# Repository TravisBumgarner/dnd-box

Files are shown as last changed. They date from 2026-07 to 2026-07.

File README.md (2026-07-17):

# dnd_box — DND status cube

A battery-powered "Do Not Disturb" cube built on a **Seeed XIAO ESP32-C6**. An
**ADXL345** accelerometer senses which face points **up**, and the matching colored
LED lights to show your status:

| Face up | LED | Meaning |
| --- | --- | --- |
| Front | 🔴 Red | Busy / do not disturb |
| Left | 🟢 Green  | Available |
| Right | 🟡 Yellow | Semi-Available |
| Back | 🔵 Blue | Who knows |
| Top | — (off) | Idle / off |
| Bottom  | — (off) | Charge side (USB-C port) |

Only one LED is lit at a time. Charging is independent of status — the cube keeps
showing the orientation color while plugged in. After sitting idle on an off side for
30 s it **deep-sleeps** and **wakes on movement** (ADXL345 activity interrupt → D0).

## Wiring

Wiring diagram

LEDs are **active-HIGH**: `GPIO → 330Ω → LED anode`, `LED cathode → GND`. The ADXL345
runs in I²C mode — tie its `CS→VCC` and `SDO→GND` (address `0x53`); most breakouts do
this already.

| From (XIAO) | GPIO | To |
| --- | ---- | -- |
| D7  | 17 | 330Ω → Blue LED → GND |
| D8  | 19 | 330Ω → Green LED → GND |
| D9  | 20 | 330Ω → Yellow LED → GND |
| D10 | 18 | 330Ω → Red LED → GND |
| D4 · SDA | 22 | ADXL345 SDA |
| D5 · SCL | 23 | ADXL345 SCL |
| D0 · INT | 0  | ADXL345 INT1 (must be an LP GPIO for deep-sleep wake) |
| 3V3 | — | ADXL345 VCC (+ CS) |
| GND | — | ADXL345 GND (+ SDO), LED cathodes |
| BAT+ / BAT− | — | LiPo battery (charges via USB-C) |

## One-time setup

```sh
./setup.sh
```

Installs `arduino-cli` (Homebrew), the Espressif `esp32` core, and confirms the board.

## Calibrate

Every cube's "up" vectors differ, so record them once:

```sh
./upload.sh calibrate
```

This flashes the calibration tool and walks you through it: for each side, rotate so
that face is **up**, hold still, and press **Enter**. It captures the vectors straight
into `firmware/config.h` and then flashes the cube app for you — no copy-paste, no
second command.

> The driver needs `pyserial`; `setup.sh` creates a `.venv` with it. To debug the raw
> tool instead (print the block to the monitor, no auto-write), use
> `./upload.sh calibrate -m` and press **Enter** once to start.

## Run

```sh
./upload.sh -m
```

Builds and flashes `firmware/`, then opens the serial monitor (115200). You'll see
`side = RED`, `side = GREEN`, … as you turn the cube, with the matching LED lit.

## Tuning

In `firmware/firmware.ino`:

- `SLEEP_TIMEOUT_MS` — idle time on an off side before deep sleep (default 30 s).
- `MATCH_MIN_CONF` — how square-on a face must be to register (dot product, 0.90).
- `DEBOUNCE` — stable reads before switching sides (anti-flicker).

Wake sensitivity is `ACT_THRESH` in `libraries/DndBox/DndBox.h` (62.5 mg/LSB).

## Troubleshooting

- **All LEDs flashing on boot** → ADXL345 not detected. Check SDA/SCL/power and that
  `CS→VCC`, `SDO→GND`.
- **"Resource busy" / could not open port** → a serial monitor is still holding the
  port. Press **Ctrl-C** in the monitor to exit before re-uploading. (`upload.sh` also
  auto-closes anything holding the port before it flashes.)
- **Port not found** → `arduino-cli board list` shows the current `/dev/cu.usbmodem*`.
- **Upload won't start** → hold **BOOT**, tap **RESET**, release **BOOT**, re-run.

## Enclosure (3D print)

The enclosure is modeled in Onshape:
**[dnd-box cube](https://cad.onshape.com/documents/d81f327aa5f0460d118114fa/w/1cc042a8fa5a631b072c03ca/e/43ef30c76cb572ed67bed12c)**.
It's a hollow cube shell plus a friction-fit lid, with 5 mm LED holders (behind thin
diffuser windows) on the four side walls, wire channels down each wall, protoboard
standoffs, and a USB-C cutout. Export STLs from Onshape (right-click a part →
**Export**) to slice and print.

**Printing**
- Shell prints as-is (open side up). Print the **lid upside-down** (skirt pointing up).
- Print the shell in **translucent/white** filament so the LEDs glow the face instead
  of showing a hot dot.
- Tune the lid skirt clearance to your printer if the lid is too loose/tight.

**Assembly**
1. Screw the protoboard to the four standoffs (M2.5 self-tappers into the pilot holes).
2. Mount the XIAO with its USB-C at the cutout wall; wire the LEDs on flying leads into
   the holders (nose against the diffuser). Chain one **common ground** across all four
   LED cathodes to save wires.
3. Anchor the LED wires where they leave the board (strain relief), then tuck them in
   the channels.
4. Close the lid, then **calibrate** (`./upload.sh calibrate`) — do it last, since the
   mapping depends on the ADXL345's final mounted orientation.

## Layout

| Path | Purpose |
| ---- | --- |
| `firmware/firmware.ino` | Cube app: orientation → LED, sleep/wake |
| [Onshape doc](https://cad.onshape.com/documents/d81f327aa5f0460d118114fa/w/1cc042a8fa5a631b072c03ca/e/43ef30c76cb572ed67bed12c) | Enclosure CAD (shell + lid); export STLs to print |
| `firmware/config.h` | Calibration data (generated by the calibrate tool) |
| `calibrate/calibrate.ino` | Walks each side, emits a `config.h` block |
| `tools/calibrate_driver.py` | Drives the calibrate serial session, writes `config.h` |
| `component_tests/` | Standalone sketches to exercise one component in isolation |
| `libraries/DndBox/DndBox.h` | Pin map, ADXL345 driver, orientation match, sleep |
| `setup.sh` | One-time toolchain + core install (+ calibration `.venv`) |
| `upload.sh` | `./upload.sh [firmware\|calibrate\|<component_test>] [port] [-m]` |
| `wiring.svg` | The diagram above |
| `bin/python` | Shim so build tools find `python` |

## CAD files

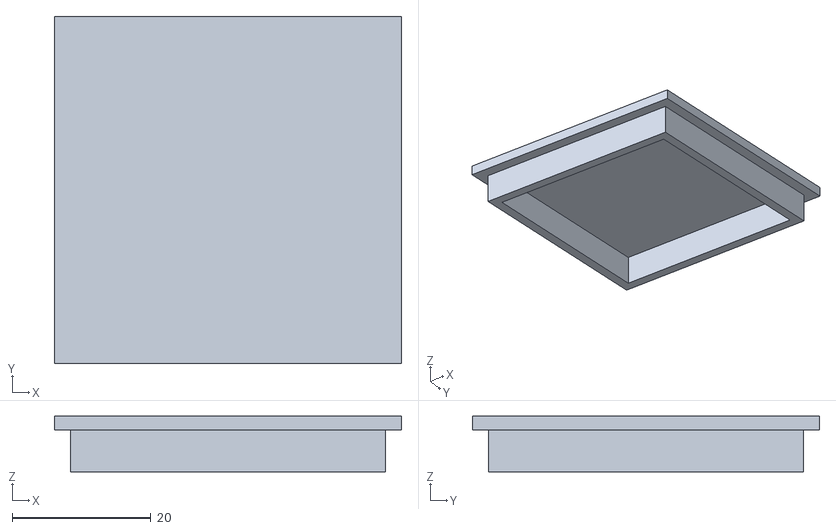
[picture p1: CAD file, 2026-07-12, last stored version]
enclosure/dnd_cube_lid.stl
50.0 x 50.0 x 8.00

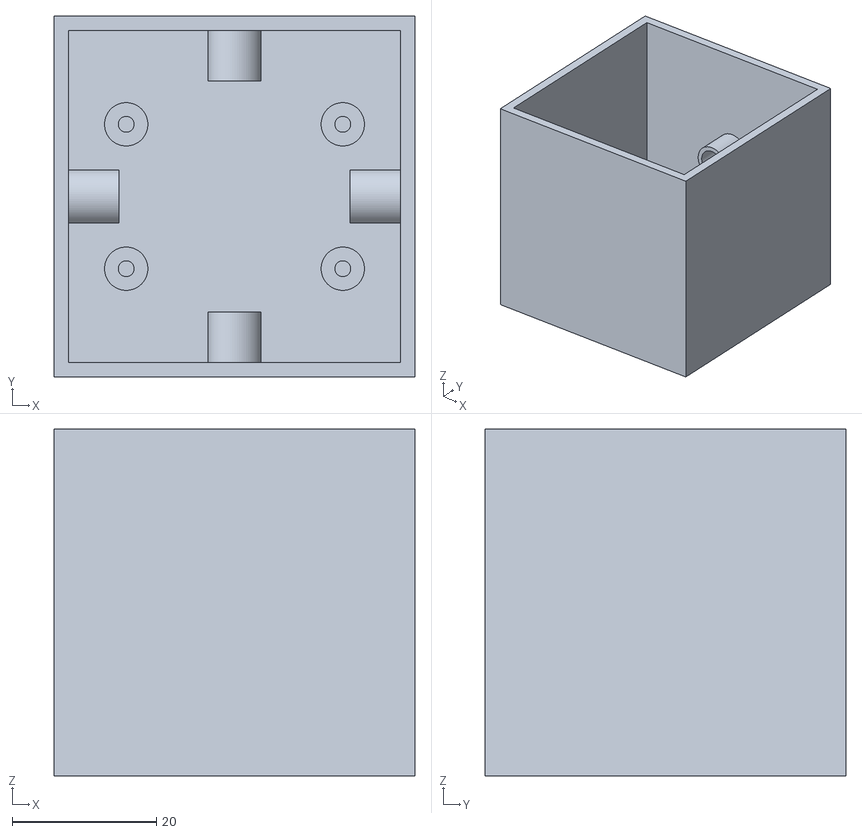
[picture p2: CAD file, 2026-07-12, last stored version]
enclosure/dnd_cube_shell.stl
50.0 x 50.0 x 48.0

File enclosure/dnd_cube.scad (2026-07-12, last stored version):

// dnd_cube.scad — parametric enclosure for the DND status cube.
//
// A hollow cube (shell) with a friction-fit lid. The 4 side walls each hold a 5 mm
// LED behind a thin diffuser window; wire channels run down each wall to a protoboard
// that sits on standoffs; one wall has a USB-C cutout for charging/flashing.
//
// Faces (before you calibrate — color assignment is whatever you wire, calibration
// sorts it out):  +Y / +X / -Y / -X = the four LED faces.  Top = lid (off).  Floor
// = the "bottom / charge" face where the USB-C cutout lives.
//
// Export: set `part` to "shell" or "lid", Render (F6), then export STL.
//   Print the LID upside-down (skirt up) — it's modeled plate-down for preview.

part = "both";        // "shell" | "lid" | "both"

// ---------------- Overall ----------------
c        = 50;        // outer edge length (mm)
wall     = 2;         // wall / floor thickness
$fn      = 72;
eps      = 0.05;

// ---------------- LEDs ----------------
led_dia   = 5.0;      // LED body diameter (5 mm through-hole)
led_clear = 0.5;      // bore clearance around the LED
led_wall  = 1.2;      // holder tube wall thickness
led_boss  = 8;        // holder tube length (LED seating depth)
led_z     = 25;       // LED center height above the floor (= cube face center)
diffuser  = 1.0;      // wall left over the LED = the glow window (thinner = brighter)

// ---------------- Protoboard ----------------
board_l     = 30;     // board length (X)
board_w     = 20;     // board width  (Y)
board_cx    = 0;      // board center offset X (shift toward the USB wall if needed)
board_cy    = 0;      // board center offset Y
standoff_h  = 6;      // board height above the floor
standoff_od = 6;      // standoff outer diameter
standoff_id = 2.2;    // pilot hole for an M2.5 self-tapping screw

// ---------------- USB-C cutout ----------------
usb_angle = 90;       // which wall: 0=+Y, 90=+X, 180=-Y, 270=-X
usb_w     = 11;       // width  (size for the cable's molded boot, not just the plug)
usb_h     = 6;        // height
usb_z     = 11;       // center height (≈ standoff_h + board + connector)

// ---------------- Wire channels ----------------
chan_w = 3;           // channel width
chan_d = 1.2;         // channel depth into the wall

// ---------------- Lid ----------------
lid_th    = wall;     // top plate thickness (counts toward total height)
lid_skirt = 6;        // depth of the plug-in skirt
fit       = 0.3;      // clearance between skirt and cavity (tune for your printer)

// ---------------- Derived ----------------
inner   = c - 2*wall;
shell_h = c - lid_th; // walls stop short so the lid plate completes the cube

// ======================================================================
module led_holder() {                 // tube on the +Y wall, LED points +Y
  translate([0, c/2 - diffuser - led_boss, led_z])
    rotate([-90,0,0])
      cylinder(h = led_boss, d = led_dia + 2*led_wall);
}
module led_bore() {                    // bore from outside, leaving `diffuser` mm
  translate([0, c/2 - diffuser, led_z])
    rotate([90,0,0])
      cylinder(h = led_boss + wall + eps, d = led_dia + led_clear);
}
module wire_channel() {                // groove down the +Y inner wall to board level
  z0 = wall + standoff_h;
  translate([-chan_w/2, inner/2 - chan_d, z0])
    cube([chan_w, chan_d + eps, led_z - z0]);
}
module usb_cut() {                     // hole through the +Y wall
  translate([-usb_w/2, inner/2 - eps, usb_z - usb_h/2])
    cube([usb_w, wall + 2*eps, usb_h]);
}
module standoffs() {
  for (sx = [-1, 1], sy = [-1, 1])
    translate([board_cx + sx*board_l/2, board_cy + sy*board_w/2, wall])
      difference() {
        cylinder(h = standoff_h, d = standoff_od);
        translate([0,0,-eps]) cylinder(h = standoff_h + 2*eps, d = standoff_id);
      }
}

module shell() {
  difference() {
    union() {
      difference() {                                   // hollow box, open top
        translate([-c/2, -c/2, 0]) cube([c, c, shell_h]);
        translate([-inner/2, -inner/2, wall]) cube([inner, inner, shell_h]);
      }
      for (a = [0:90:270]) rotate([0,0,a]) led_holder();
      standoffs();
    }
    for (a = [0:90:270]) rotate([0,0,a]) { led_bore(); wire_channel(); }
    rotate([0,0,usb_angle]) usb_cut();
  }
}

module lid() {                          // plate at z=0..lid_th, skirt hangs below
  s = inner - 2*fit;
  union() {
    translate([-c/2, -c/2, 0]) cube([c, c, lid_th]);
    translate([-s/2, -s/2, -lid_skirt])
      difference() {
        cube([s, s, lid_skirt]);
        translate([wall, wall, -eps]) cube([s - 2*wall, s - 2*wall, lid_skirt + 2*eps]);
      }
  }
}

// ======================================================================
if (part == "shell" || part == "both") shell();
if (part == "lid") lid();
if (part == "both") translate([c + 12, 0, lid_skirt]) lid();   // preview beside shell

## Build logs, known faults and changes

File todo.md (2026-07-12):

We're going to build DND device. 

It'll have a battery attached.

4 LEDs -> red, green, yellow, blue. 
It'll use an ADXL345.

I imagine the sides will be one color per LED - front left right and back. Top will be off, and bottom will be to charge. Let's make it so you can still set a color while it's charging too.

We'll want a calibration script to set the sides as well. So a "Put it on red, then hit enter" and it'll output a list of config params that can then be uploaded to the device.

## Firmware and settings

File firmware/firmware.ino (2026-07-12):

// firmware.ino — DND status cube (Seeed XIAO ESP32-C6).
//
// Reads the ADXL345 to decide which face points UP, then lights that side's LED.
// TOP / BOTTOM sides have no LED (off). After sitting on an "off" side for
// SLEEP_TIMEOUT_MS, the cube deep-sleeps and wakes on movement (ADXL345 INT → D0).
#include <DndBox.h>
#include "config.h"

// ───────── Tuning ─────────
static const uint32_t SLEEP_TIMEOUT_MS = 30000;  // idle-on-off-side before sleep
static const float    MATCH_MIN_CONF   = 0.90f;  // dot-product needed to accept a side
static const uint8_t  DEBOUNCE         = 4;       // stable reads before switching side
static const uint16_t LOOP_DELAY_MS    = 80;

int      currentSide = -1;   // side currently displayed
int      candidate   = -1;   // side we're debouncing toward
uint8_t  stable      = 0;
uint32_t offSince    = 0;    // millis() when we landed on an off side (0 = not off)

static bool isOffSide(int i) { return i >= 0 && SIDES[i].ledPin < 0; }

void showSide(int i) {
  ledSet(i >= 0 ? SIDES[i].ledPin : -1);
  Serial.printf("side = %s\n", i >= 0 ? SIDES[i].name : "?");
}

// Flash all LEDs briefly so a hardware/wiring fault is obvious.
void errorBlink() {
  for (;;) {
    for (int p : DND_LEDS) digitalWrite(p, HIGH);
    delay(150);
    ledsAllOff();
    delay(150);
    Serial.println("ADXL345 not found — check SDA/SCL/power.");
  }
}

void setup() {
  Serial.begin(115200);
  ledsInit();
  if (!adxlBegin()) errorBlink();
  Serial.println(wokeFromMotion() ? "woke from motion" : "power-on / reset");
}

void loop() {
  float x, y, z, conf;
  adxlReadAvg(x, y, z, 16);
  int b = bestSide(SIDES, NUM_SIDES, x, y, z, &conf);
  if (conf < MATCH_MIN_CONF) b = currentSide;   // ambiguous tilt → hold current

  if (b == candidate) { if (stable < 255) stable++; }
  else { candidate = b; stable = 0; }

  if (stable >= DEBOUNCE && b != currentSide) {
    currentSide = b;
    showSide(currentSide);
  }

  // Sleep after being idle on an off side (charging keeps working — motion wakes it).
  if (isOffSide(currentSide)) {
    if (offSince == 0) offSince = millis();
    else if (millis() - offSince > SLEEP_TIMEOUT_MS) {
      Serial.println("idle on off side → deep sleep");
      Serial.flush();
      deviceSleep();  // returns only after a reset on the next wake
    }
  } else {
    offSince = 0;
  }

  delay(LOOP_DELAY_MS);
}

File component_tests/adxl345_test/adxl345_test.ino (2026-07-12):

// adxl345_test.ino — isolated ADXL345 read test (Seeed XIAO ESP32-C6).
//
// Self-contained: no DndBox.h / config.h dependency. Talks to the ADXL345 directly
// over I2C so you can confirm the sensor and wiring work on their own, apart from
// the rest of the cube firmware.
//
// Expected: on boot, "ADXL345 found (DEVID 0xE5)" then a stream of x/y/z readings
// in g. At rest, one axis should read ~±1.00 g (gravity) and the others ~0.00 g.
// Rotate the board and watch which axis swaps.
//
// Upload with arduino-cli, e.g.:
//   arduino-cli compile --fqbn esp32:esp32:XIAO_ESP32C6 component_tests/adxl345_test
//   arduino-cli upload  --fqbn esp32:esp32:XIAO_ESP32C6 -p /dev/tty.usbmodem* component_tests/adxl345_test
//   arduino-cli monitor -p /dev/tty.usbmodem* -c baudrate=115200

#include <Wire.h>

// ── Pin map (matches DndBox.h / XIAO ESP32-C6) ──
#define PIN_SDA  D4   // GPIO22
#define PIN_SCL  D5   // GPIO23

// ── ADXL345 registers ──
#define ADXL345_ADDR            0x53   // SDO tied to GND
#define ADXL345_REG_DEVID       0x00   // reads 0xE5
#define ADXL345_REG_BW_RATE     0x2C
#define ADXL345_REG_POWER_CTL   0x2D
#define ADXL345_REG_DATA_FORMAT 0x31
#define ADXL345_REG_DATAX0      0x32

static void adxlWrite(uint8_t reg, uint8_t val) {
  Wire.beginTransmission(ADXL345_ADDR);
  Wire.write(reg);
  Wire.write(val);
  Wire.endTransmission();
}

static uint8_t adxlRead(uint8_t reg) {
  Wire.beginTransmission(ADXL345_ADDR);
  Wire.write(reg);
  Wire.endTransmission(false);
  Wire.requestFrom((int)ADXL345_ADDR, 1);
  return Wire.available() ? Wire.read() : 0;
}

// Read one sample in g (full-res = 256 LSB/g).
static void adxlReadOnce(float& x, float& y, float& z) {
  Wire.beginTransmission(ADXL345_ADDR);
  Wire.write(ADXL345_REG_DATAX0);
  Wire.endTransmission(false);
  Wire.requestFrom((int)ADXL345_ADDR, 6);
  int16_t xi = Wire.read() | (Wire.read() << 8);
  int16_t yi = Wire.read() | (Wire.read() << 8);
  int16_t zi = Wire.read() | (Wire.read() << 8);
  x = xi / 256.0f;
  y = yi / 256.0f;
  z = zi / 256.0f;
}

void setup() {
  Serial.begin(115200);
  while (!Serial && millis() < 3000) { /* wait for USB serial */ }

  Wire.begin(PIN_SDA, PIN_SCL);

  uint8_t id = adxlRead(ADXL345_REG_DEVID);
  if (id != 0xE5) {
    Serial.printf("ADXL345 NOT found — DEVID read 0x%02X (expected 0xE5).\n", id);
    Serial.println("Check SDA/SCL wiring, 3V3 power, and that SDO is tied to GND (addr 0x53).");
    return;  // fall through to loop, which will just report the failure
  }
  Serial.println("ADXL345 found (DEVID 0xE5).");

  adxlWrite(ADXL345_REG_DATA_FORMAT, 0x08);  // FULL_RES, ±2g
  adxlWrite(ADXL345_REG_BW_RATE, 0x0A);      // 100 Hz, normal power
  adxlWrite(ADXL345_REG_POWER_CTL, 0x08);    // measure
}

void loop() {
  if (adxlRead(ADXL345_REG_DEVID) != 0xE5) {
    Serial.println("ADXL345 unreachable — check wiring/power.");
    delay(1000);
    return;
  }
  float x, y, z;
  adxlReadOnce(x, y, z);
  float mag = sqrtf(x * x + y * y + z * z);
  Serial.printf("x=%+6.3f  y=%+6.3f  z=%+6.3f  |g|=%5.3f\n", x, y, z, mag);
  delay(200);
}

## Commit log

2026-07-12 Initial commit: DND status cube firmware, enclosure, and tooling
    Seeed XIAO ESP32-C6 cube that reads an ADXL345 to light a per-face LED,
    with calibrate tool, isolation component tests, and OpenSCAD enclosure.
    LEDs on D7/D8/D9/D10; upload.sh auto-detects the serial port.
    [dnd_cube.scad, dnd_cube_lid.stl, dnd_cube_shell.stl]
2026-07-16 Automate calibration and fix red/blue LED mapping
    Make `./upload.sh calibrate` a one-shot flow: flash the calibrate sketch,
    drive its serial walkthrough via a new pyserial-based driver, capture the
    emitted block straight into firmware/config.h, then flash the firmware — no
    copy-paste, no second command. `./upload.sh calibrate -m` still does the raw
    flash+monitor for debugging.
    - tools/calibrate_driver.py: serial bridge that writes config.h
    - calibrate.ino: wait for a host byte before printing so the C6's always-on
    USB serial doesn't drop the intro/first prompt
    - setup.sh: create the .venv with pyserial
    - DndBox.h: map PIN_LED_RED->D10, PIN_LED_BLUE->D7 to match how the LEDs are
    physic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
    [calibrate.ino, calibrate_driver.py]
2026-07-17 Move enclosure CAD to Onshape; remove OpenSCAD/STL files
    The enclosure is now maintained in Onshape, so drop the OpenSCAD source and its
    exported STLs and point the README (Enclosure section + Layout table) at the
    Onshape document instead. Assembly steps kept, minus the OpenSCAD-variable
    references.
    [dnd_cube.scad, dnd_cube_lid.stl, dnd_cube_shell.stl]
